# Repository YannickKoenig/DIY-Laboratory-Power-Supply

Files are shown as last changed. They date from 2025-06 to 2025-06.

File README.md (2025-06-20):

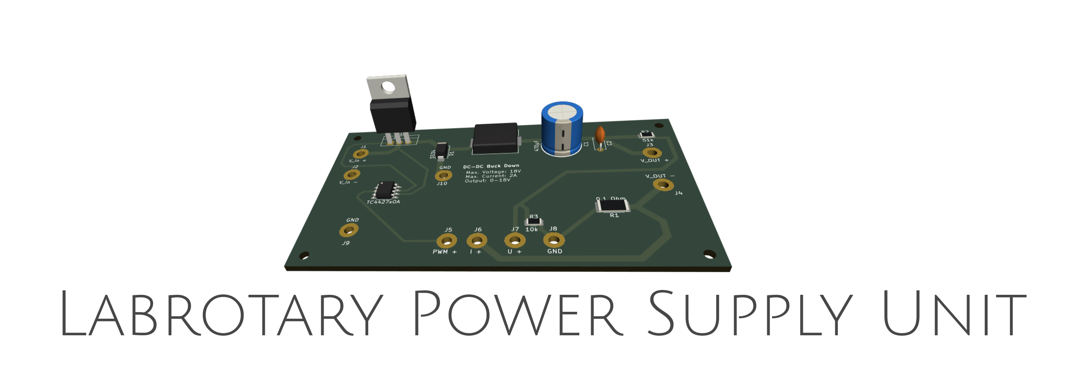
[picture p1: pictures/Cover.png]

# DIY Laboratory Power Supply Unit
A simple, microcontroller-based PWM buck converter power supply, designed to provide precise voltage control and current measurement. The output voltage is easily adjustable using a rotary encoder for accurate and intuitive input. This project is compact, affordable, and perfect for DIY laboratory power supply applications.

## Features
- Voltage regulation via PWM buck converter
- User-friendly voltage adjustment using a rotary encoder
- Real-time display of voltage and current
- Custom PCB Boards
- Compact and cost-effective design (~9€)

## Table of Contents  
- [BOM](#bom)
- [Assembly](#assembly)  
- [Usage](#usage)  
- [Contributing](#contributing)  
- [License](#license)
- [Schematics](#schematics)

## Bill of Materials (BOM)

| Item | Description | Quantity | Price | Total |
|---|---|---|---|---|
| KY-040 | Rotary Encoder | 1 | 0,89 €  | 0,89 €  |
| IRLZ44N | MOSFET-Transistor (TO-220) | 1 | 0,22 €  | 0,22 €  |
| Fuse (2A) | 5x20mm Glass Fuse | 1 | 0,03 €  | 0,03 €  |
| SS34 | Schottky Diode | 1 | 0,02 €  | 0,02 €  |
| TM1637 | 4-digit 7-segment LED Display | 2 | 1,90 €  | 3,80 €  |
| DC Plug | - | 1 | 0,24 €  | 0,24 €  |
| Power Switch | - | 1 | 0,12 €  | 0,12 €  |
| TC4427 | MOSFET Driver (SOP-8) | 1 | 0,29 €  | 0,29 €  |
| Buck Converter PCB | Custom PCB for Buck Converter | 1 | 0,08 €  | 0,08 €  |
| Frontend PCB (optional)| Custom PCB for Input & Displays | 1 | 0,80 €  | 0,80 €  |
| Raspberry Pi Pico | Microcontroller | 1 | 2,00 €  | 2,00 €  |
| Electrolytic Capacitor  | 470µF | 1 | 0,30 €  | 0,30 €  |
| Ceramic Capacitor | 1µF | 1 | 0,10 €  | 0,10 €  |
| Inductor | CD75, 47UH | 1 | 0,10 €  | 0,10 €  |
| SMD Resistor | Values 51k and 10k (1206) | 2 | 0,01 €  | 0,02 €  |
| SMD Resistor | Value 0.1 Ohm (2512) | 1 | 0,01 €  | 0,01 €  |

**Total: 9,01 €**

## Assembly
1. **Order the PCBs**:
For easier and cleaner assembly, it is recommended to order the PCBs from manufacturers like JLCPCB, PCBWAY, or AllPCB. Both the Buck Converter PCB and the optional Frontend PCB can be used. Just upload the appropriate Gerber files ([buckdown-pcb](hardware/electrical/buck-converter/Gerber), [frontend-pcb](hardware/electrical/frontend/Gerber))
2. **Solder the components**:
Carefully solder all the required components. The project includes both SMD and THT parts, so make sure you have the right tools and technique.
3. **Flash the microcontroller**:
-   Connect the Raspberry Pi Pico to your computer while holding the **BOOTSEL** button during startup.
-   You can either compile the firmware yourself or simply upload the precompiled `.uf2` file provided in the **releases** section.

4. **Connect the wiring**:
-   Connect the **Buck Converter PCB** and the **Frontend PCB** (if used) using the following connections:
    
    -   `GND` → `GND`
        
    -   `I+` → `I_in`
        
    -   `U+` → `U_in`
        
-   Connect the output of the Buck Converter:
    
    -   `V_out+` → Positive output terminal (e.g., banana plug).
        
    -   `V_out-` → Negative output terminal (e.g., banana plug).

You can use banana plugs, terminal blocks, or any other suitable connectors for your output.

-   If using the **Frontend PCB**, connect both **TM1637 displays** and the **rotary encoder** to the appropriate headers.
    
-   Make sure to add a **fuse (e.g., 2A)** to protect your circuit from potential damage.
    
-   To power the **Raspberry Pi Pico**, you can either:
    
    -   Power it via **USB**, or
        
    -   Use a separate **buck converter module** (e.g., LM2596S) connected in parallel with the DC input.

## Usage
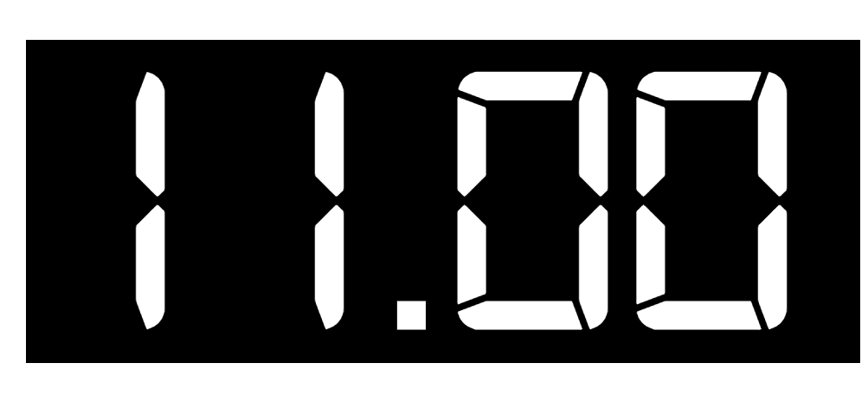
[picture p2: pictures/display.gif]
display


To adjust the output voltage:

- Turn the rotary encoder **left** to decrease the selected digit.
- Turn it **right** to increase the selected digit.
- Press the rotary encoder to switch between digits.

You can fine-tune the PI controller parameters (`K_P` and `K_I`) experimentally in the firmware to improve voltage regulation stability and response. See [RegulatorManager.hpp](./software/RegulatorManager.hpp) for details.

## Contributing

Contributions are welcome! Feel free to fork this project, submit pull requests, or open issues for improvements and bug fixes.

## Third-Party Libraries

This project uses the following third-party software:

- **Raspberry Pi Pico SDK**  
  Official SDK for Raspberry Pi Pico microcontroller.  
  License: BSD 3-Clause  
  [https://github.com/raspberrypi/pico-sdk](https://github.com/raspberrypi/pico-sdk)

- **TM1637_lib**  
  Library for controlling TM1637 7-segment displays.  
  License: MIT  
  [https://github.com/gavinlyonsrepo/displaylib_LED_PICO](https://github.com/gavinlyonsrepo/displaylib_LED_PICO)

## License

This project is open-source and available under the [MIT License](LICENSE.md).

## Schematics

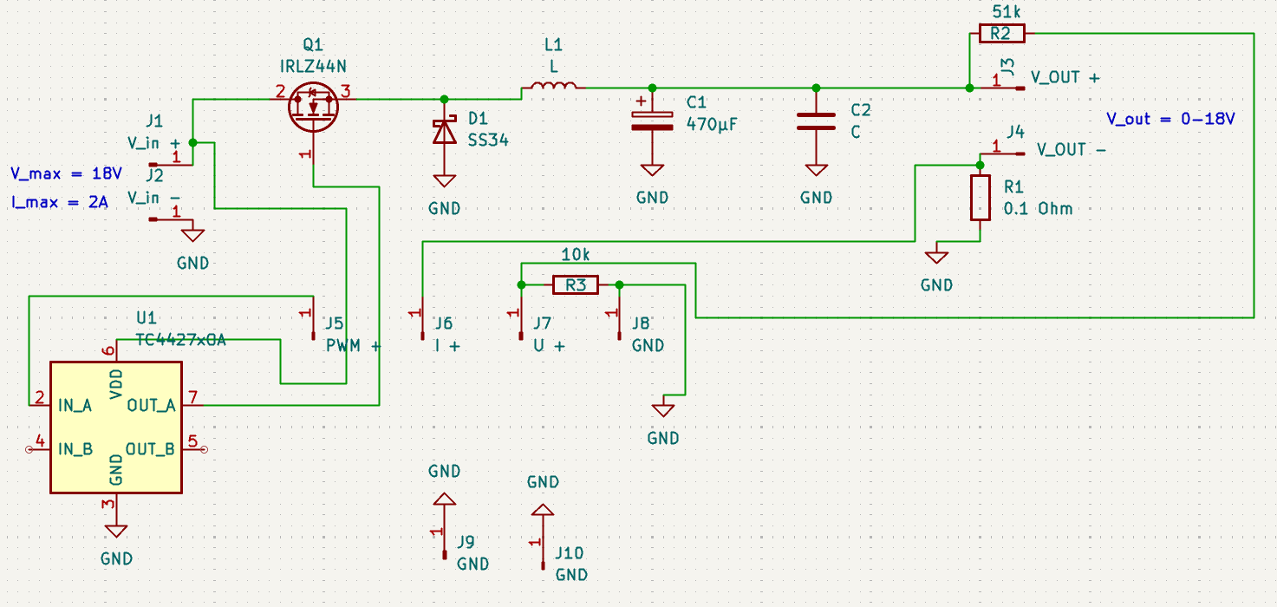
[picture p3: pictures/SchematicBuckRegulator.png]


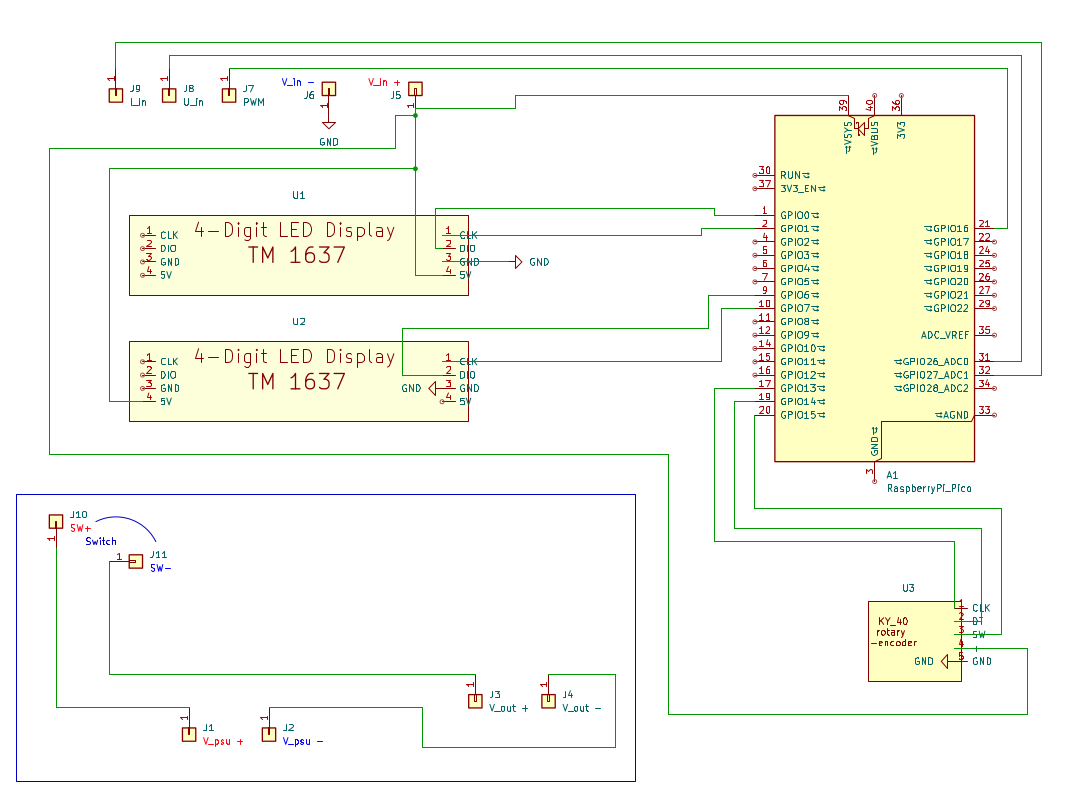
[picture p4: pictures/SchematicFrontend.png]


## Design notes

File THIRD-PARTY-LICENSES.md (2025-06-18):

# Third-Party Licenses

This project uses the following third-party software components. The licenses for these components are included below.

## Raspberry Pi Pico SDK
- License: BSD 3-Clause
- Repo: https://github.com/raspberrypi/pico-sdk

### BSD 3-Clause License Text
Copyright 2020 (c) 2020 Raspberry Pi (Trading) Ltd.

Redistribution and use in source and binary forms, with or without modification, are permitted provided that the
following conditions are met:

1. Redistributions of source code must retain the above copyright notice, this list of conditions and the following
   disclaimer.

2. Redistributions in binary form must reproduce the above copyright notice, this list of conditions and the following
   disclaimer in the documentation and/or other materials provided with the distribution.

3. Neither the name of the copyright holder nor the names of its contributors may be used to endorse or promote products
   derived from this software without specific prior written permission.

THIS SOFTWARE IS PROVIDED BY THE COPYRIGHT HOLDERS AND CONTRIBUTORS "AS IS" AND ANY EXPRESS OR IMPLIED WARRANTIES,
INCLUDING, BUT NOT LIMITED TO, THE IMPLIED WARRANTIES OF MERCHANTABILITY AND FITNESS FOR A PARTICULAR PURPOSE ARE
DISCLAIMED. IN NO EVENT SHALL THE COPYRIGHT HOLDER OR CONTRIBUTORS BE LIABLE FOR ANY DIRECT, INDIRECT, INCIDENTAL,
SPECIAL, EXEMPLARY, OR CONSEQUENTIAL DAMAGES (INCLUDING, BUT NOT LIMITED TO, PROCUREMENT OF SUBSTITUTE GOODS OR
SERVICES; LOSS OF USE, DATA, OR PROFITS; OR BUSINESS INTERRUPTION) HOWEVER CAUSED AND ON ANY THEORY OF LIABILITY,
WHETHER IN CONTRACT, STRICT LIABILITY, OR TORT (INCLUDING NEGLIGENCE OR OTHERWISE) ARISING IN ANY WAY OUT OF THE USE OF
THIS SOFTWARE, EVEN IF ADVISED OF THE POSSIBILITY OF SUCH DAMAGE.

## TM1637_lib
- License: MIT
- Repo: https://github.com/gavinlyonsrepo/displaylib_LED_PICO

### MIT License Text

 Permission is hereby granted, free of charge, to any person obtaining a copy
 of this software and associated documentation files (the "Software"), to deal
 in the Software without restriction, including without limitation the rights
 to use, copy, modify, merge, publish, distribute, sublicense, and/or sell
 copies of the Software, and to permit persons to whom the Software is
 furnished to do so, subject to the following conditions:

 The above copyright notice and this permission notice shall be included in all
 copies or substantial portions of the Software.

 THE SOFTWARE IS PROVIDED "AS IS", WITHOUT WARRANTY OF ANY KIND, EXPRESS OR
 IMPLIED, INCLUDING BUT NOT LIMITED TO THE WARRANTIES OF MERCHANTABILITY,
 FITNESS FOR A PARTICULAR PURPOSE AND NONINFRINGEMENT. IN NO EVENT SHALL THE
 AUTHORS OR COPYRIGHT HOLDERS BE LIABLE FOR ANY CLAIM, DAMAGES OR OTHER
 LIABILITY, WHETHER IN AN ACTION OF CONTRACT, TORT OR OTHERWISE, ARISING FROM,
 OUT OF OR IN CONNECTION WITH THE SOFTWARE OR THE USE OR OTHER DEALINGS IN THE
 SOFTWARE.

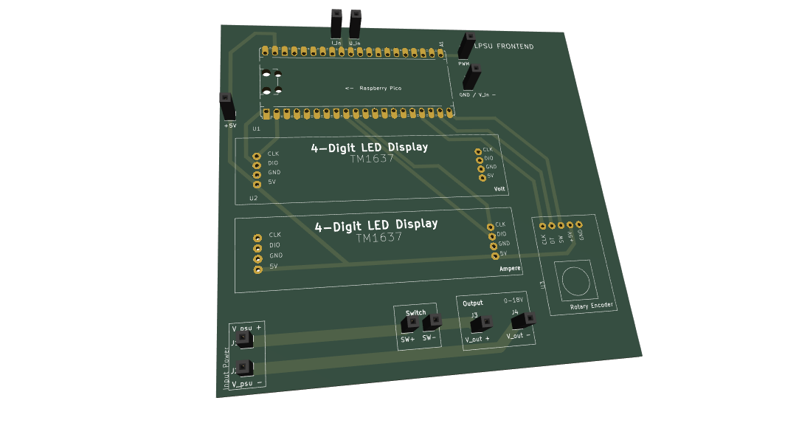
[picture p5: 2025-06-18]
pictures/FrontendPCB.png

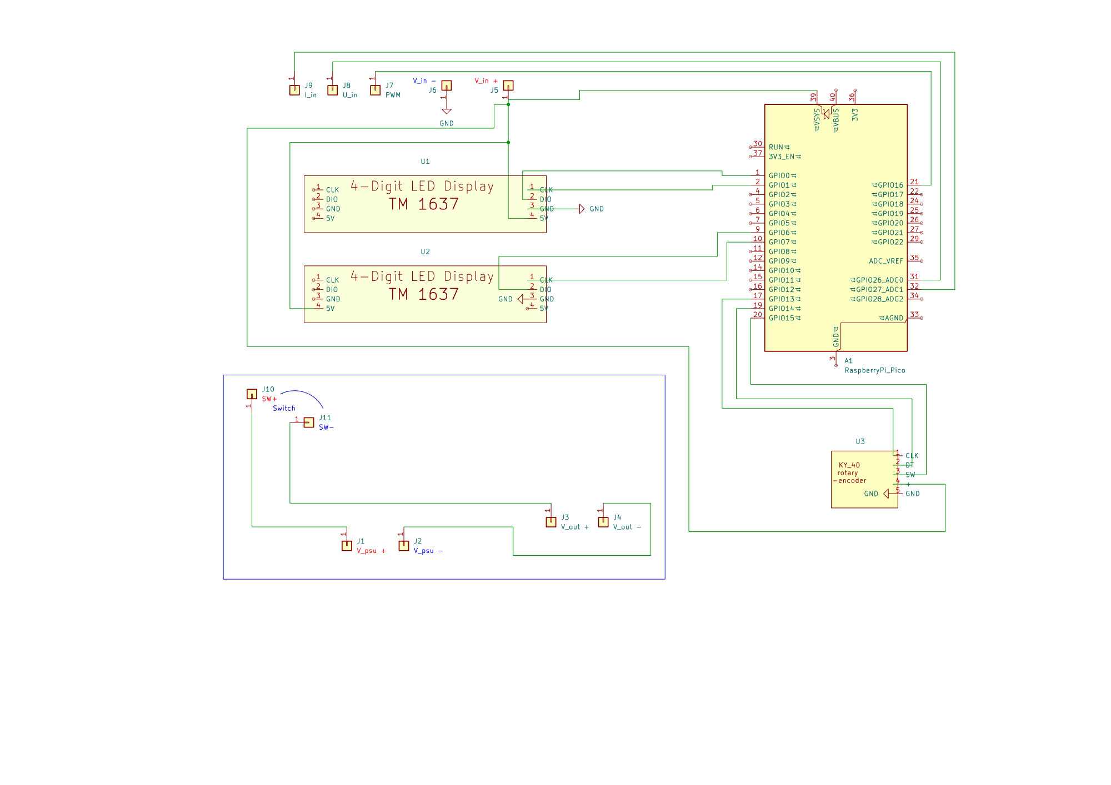
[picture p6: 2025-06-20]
pictures/Download.png

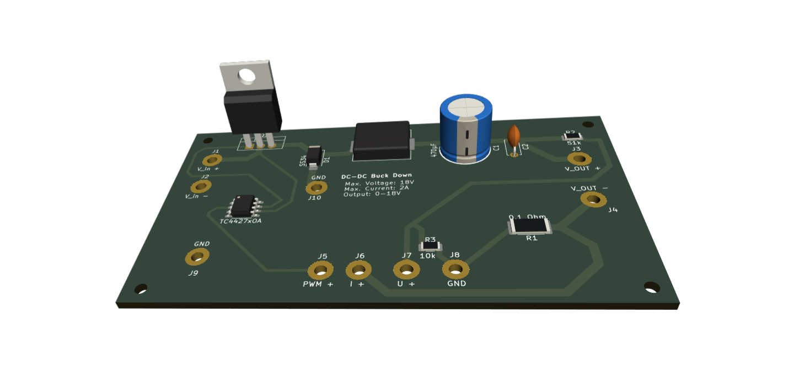
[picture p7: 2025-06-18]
pictures/BuckDownPCB.png

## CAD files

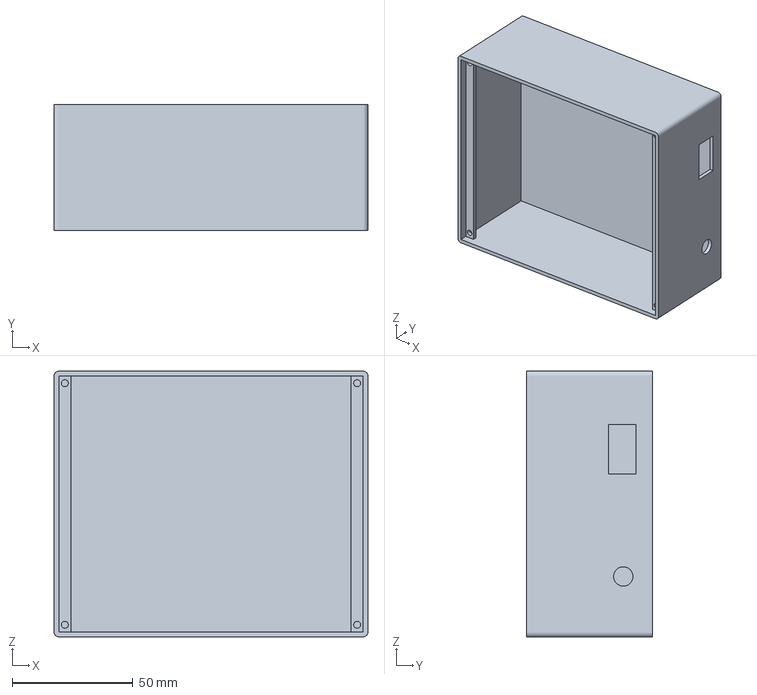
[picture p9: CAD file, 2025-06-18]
hardware/mechanical/Base.3mf
130.0 x 52.0 x 110.0 mm

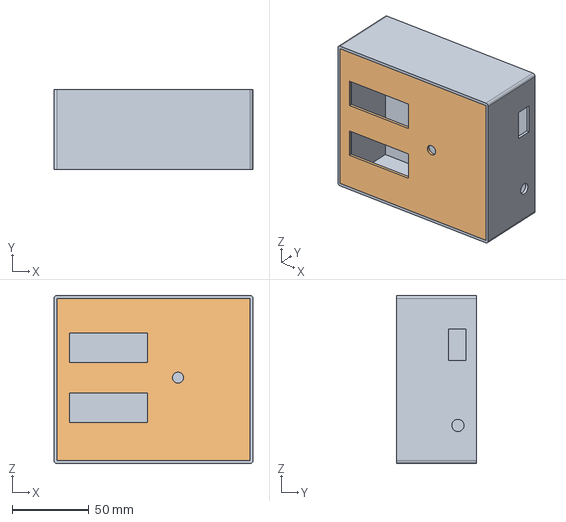
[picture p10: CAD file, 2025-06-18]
hardware/mechanical/FreeCAD.FCStd
130.0 x 52.0 x 110.0 mm
Base

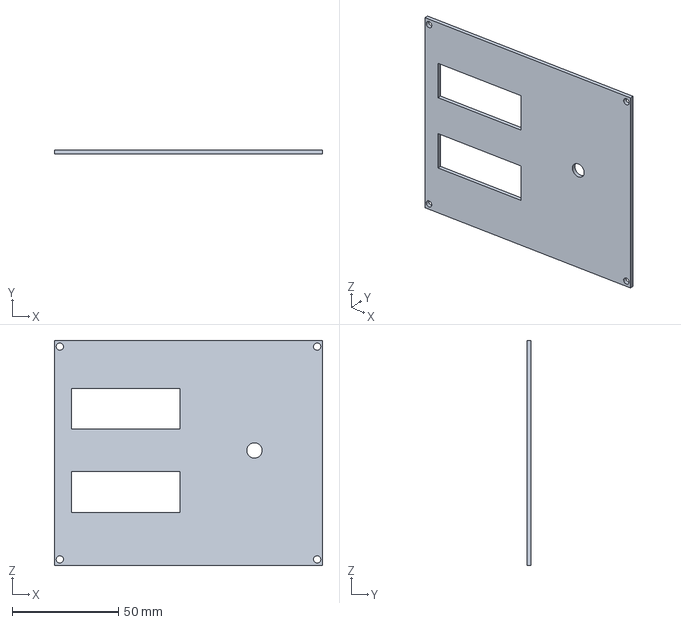
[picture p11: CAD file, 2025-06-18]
hardware/mechanical/Top.3mf
126.0 x 2.00 x 106.0 mm

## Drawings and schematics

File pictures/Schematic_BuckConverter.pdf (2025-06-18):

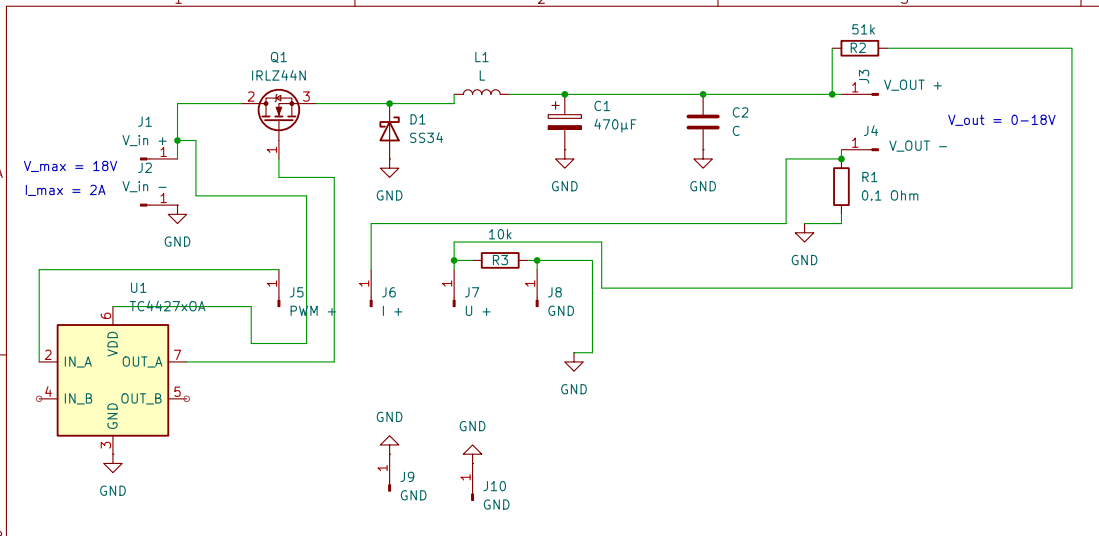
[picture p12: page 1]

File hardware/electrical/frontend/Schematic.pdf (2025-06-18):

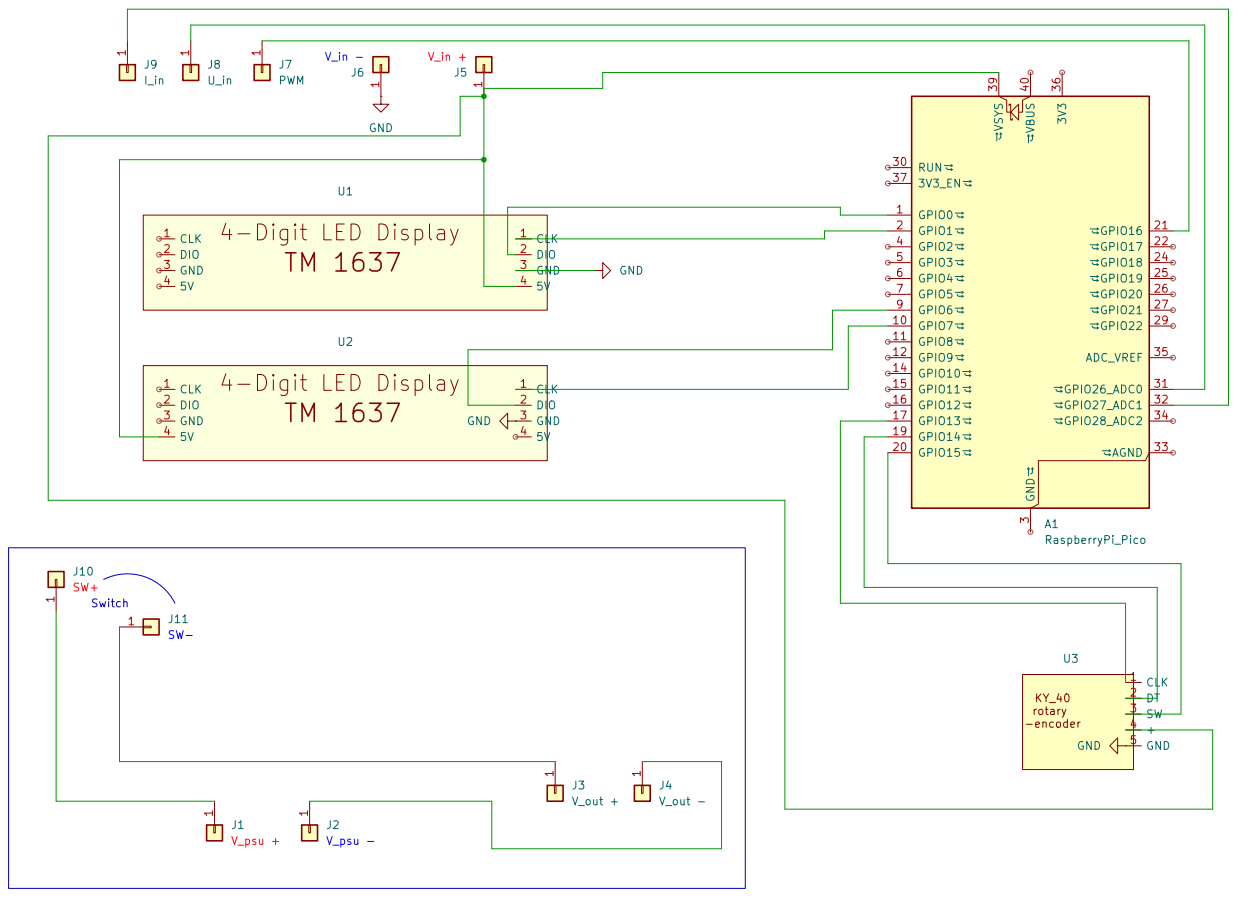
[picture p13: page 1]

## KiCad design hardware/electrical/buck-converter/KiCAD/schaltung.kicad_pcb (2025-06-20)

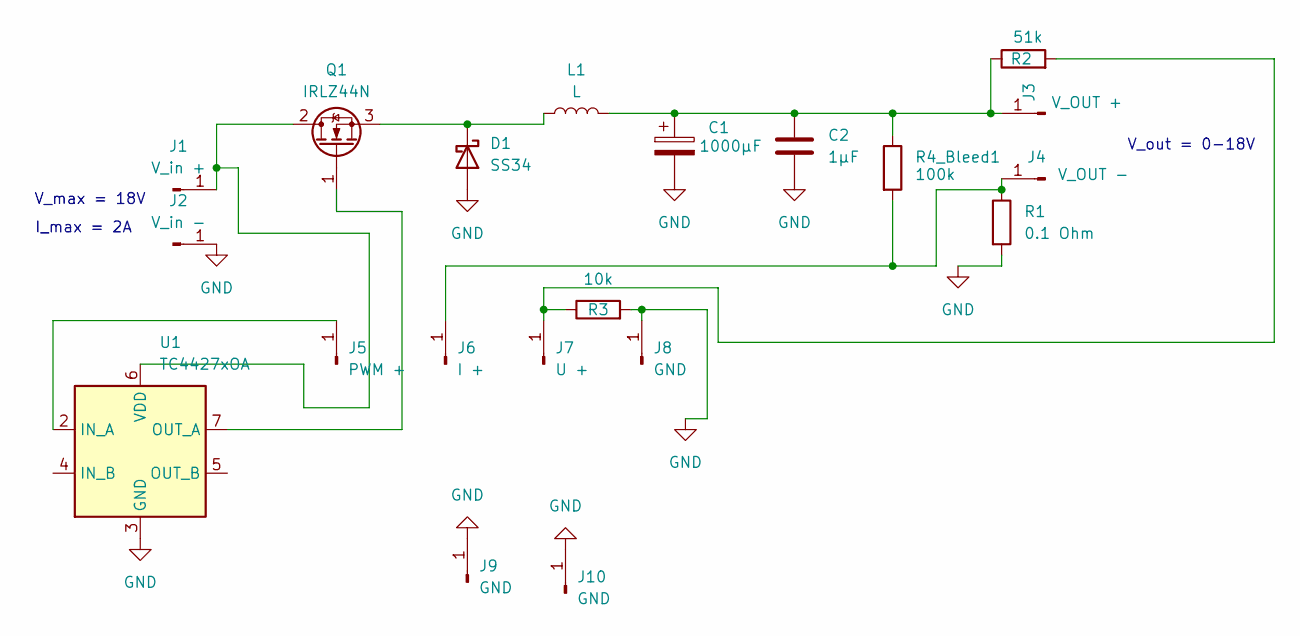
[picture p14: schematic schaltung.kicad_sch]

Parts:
C1: 1000µF; CP_Radial_D10.0mm_P5.00mm
C2: 1µF; C_Disc_D5.0mm_W2.5mm_P5.00mm
D1: SS34; D_SMA
J1: V_in +; MountingHole_2.2mm_M2_Pad
J2: V_in -; MountingHole_2.2mm_M2_Pad
J3: V_OUT +; MountingHole_2.2mm_M2_Pad
J4: V_OUT -; MountingHole_2.2mm_M2_Pad
J5: PWM +; MountingHole_2.2mm_M2_Pad
J6: I +; MountingHole_2.2mm_M2_Pad
J7: U +; MountingHole_2.2mm_M2_Pad
J8, J9, J10: GND; MountingHole_2.2mm_M2_Pad
L1: L; L_Sunlord_MWSA1003S
Q1: IRLZ44N; TO-220-3_Vertical
R1: 0.1 Ohm; R_2512_6332Metric
R2: 51k; R_1206_3216Metric
R3: 10k; R_1206_3216Metric
R4_Bleed1: 100k; R_1206_3216Metric
U1: TC4427xOA; SOIC-8_3.9x4.9mm_P1.27mm

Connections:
GND: C1.2, C2.2, D1.2 (A), J2.1, J8.1, J9.1, J10.1, R1.2, R3.2, U1.3 (GND)
unnamed: D1.1 (K), L1.1, Q1.3 (S)
unnamed: J1.1, Q1.2 (D), U1.6 (VDD)
unnamed: C1.1, C2.1, J3.1, L1.2, R2.1, R4_Bleed1.1
unnamed: J4.1, J6.1, R1.1, R4_Bleed1.2
unnamed: J5.1, U1.2 (IN_A)
unnamed: J7.1, R2.2, R3.1
unnamed: Q1.1 (G), U1.7 (OUT_A)

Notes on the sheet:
I_max = 2A
V_max = 18V
V_out = 0-18V

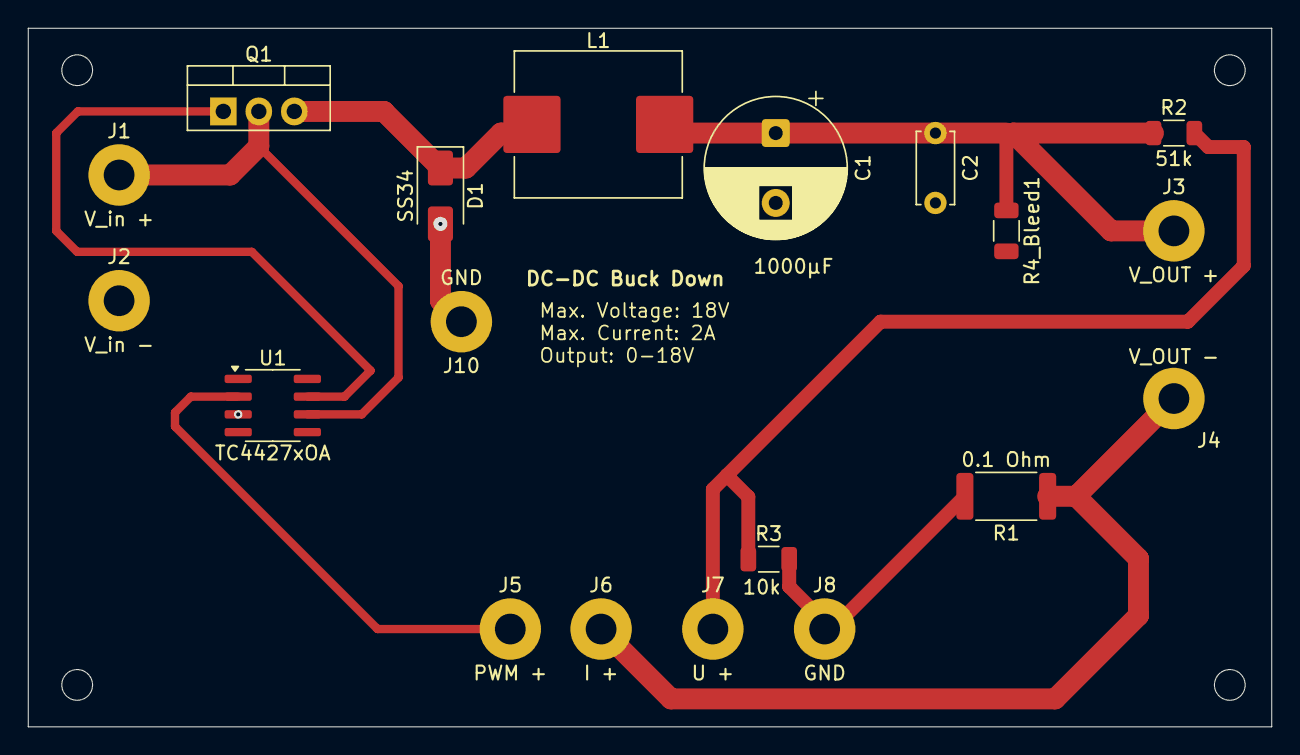
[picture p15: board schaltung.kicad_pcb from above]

Board: 2 copper layers, 89.0 x 50.0 mm, 20 parts (0 on the bottom side), 8 nets.

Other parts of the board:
REF1: MountingHole_2.2mm_M2

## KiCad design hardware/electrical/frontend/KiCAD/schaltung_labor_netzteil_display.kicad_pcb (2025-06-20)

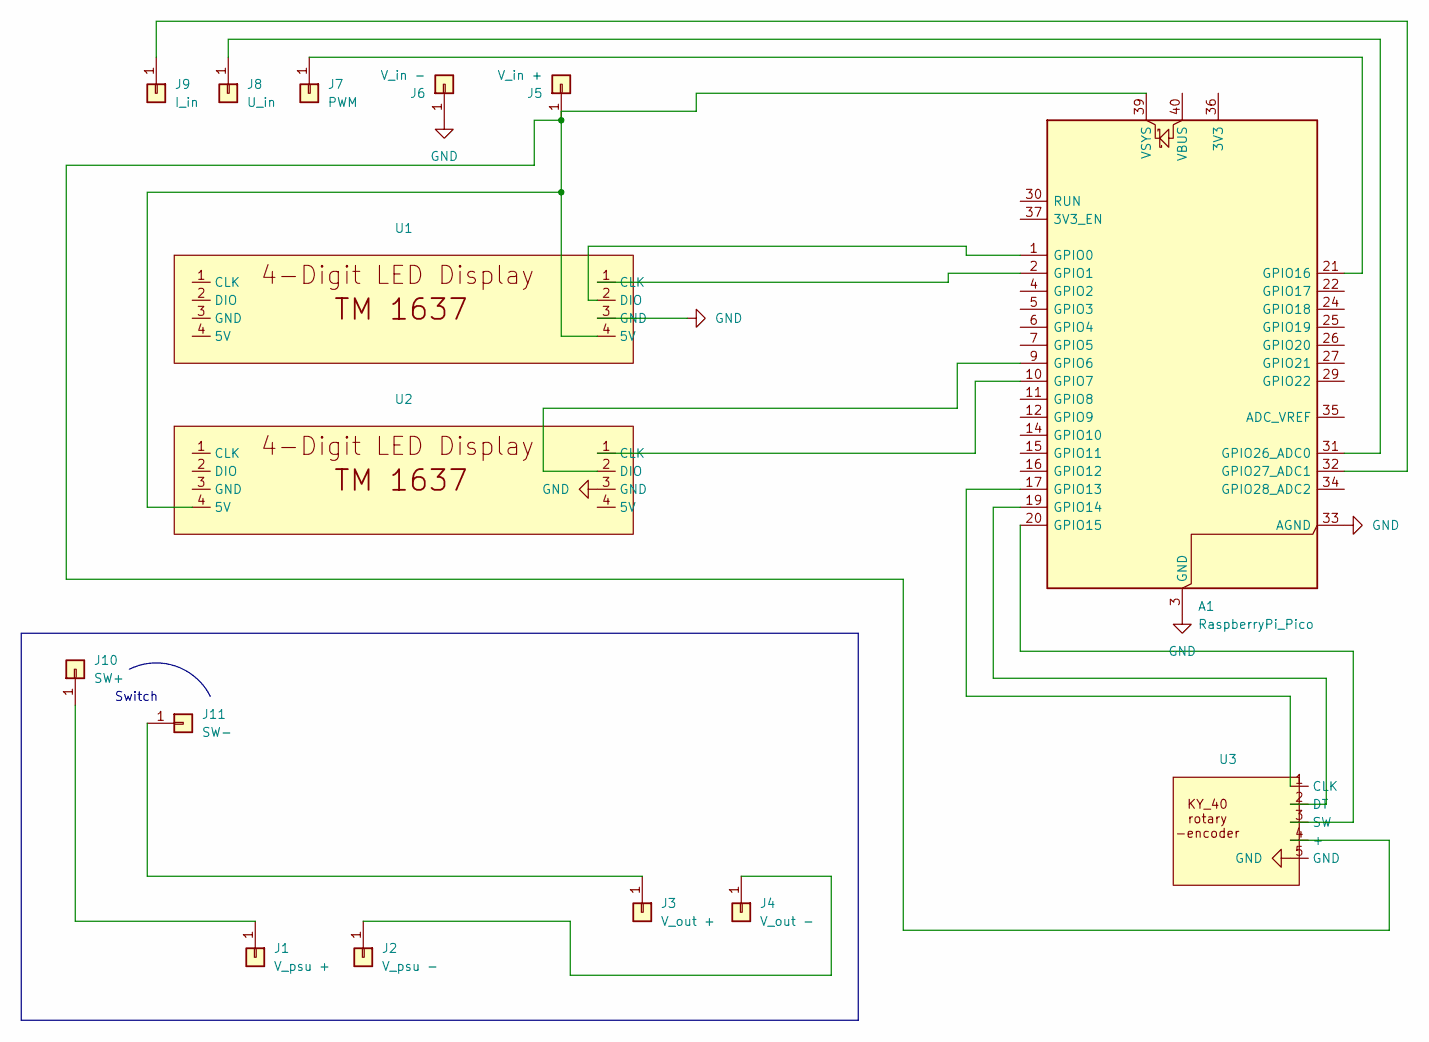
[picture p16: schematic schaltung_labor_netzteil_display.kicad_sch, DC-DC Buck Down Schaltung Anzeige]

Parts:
A1: RaspberryPi_Pico; RaspberryPi_Pico_Common_Unspecified
J1: V_psu +; PinSocket_1x01_P2.54mm_Vertical
J2: V_psu -; PinSocket_1x01_P2.54mm_Vertical
J3: V_out +; PinSocket_1x01_P2.54mm_Vertical
J4: V_out -; PinSocket_1x01_P2.54mm_Vertical
J5: V_in +; PinSocket_1x01_P2.54mm_Vertical
J6: V_in -; PinSocket_1x01_P2.54mm_Vertical
J7: PWM; PinSocket_1x01_P2.54mm_Vertical
J8: U_in; PinSocket_1x01_P2.54mm_Vertical
J9: I_in; PinSocket_1x01_P2.54mm_Vertical
J10: SW+; PinSocket_1x01_P2.54mm_Vertical
J11: SW-; PinSocket_1x01_P2.54mm_Vertical
U1, U2: TM1637
U3: KY_40

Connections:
GND: A1.3 (GND), A1.8 (GND), A1.13 (GND), A1.18 (GND), A1.23 (GND), A1.28 (GND), A1.33 (AGND), A1.38 (GND), J6.1, U1.3 (GND), U2.3 (GND), U3.5 (GND)
unnamed: A1.1 (GPIO0), U1.2 (DIO)
unnamed: A1.2 (GPIO1), U1.1 (CLK)
unnamed: A1.9 (GPIO6), U2.2 (DIO)
unnamed: A1.10 (GPIO7), U2.1 (CLK)
unnamed: A1.17 (GPIO13), U3.1 (CLK)
unnamed: A1.19 (GPIO14), U3.2 (DT)
unnamed: A1.20 (GPIO15), U3.3 (SW)
unnamed: A1.21 (GPIO16), J7.1
unnamed: A1.31 (GPIO26_ADC0), J8.1
unnamed: A1.32 (GPIO27_ADC1), J9.1
unnamed: A1.39 (VSYS), J5.1, U1.4 (5V), U2.4 (5V), U3.4 (+)
unnamed: J1.1, J10.1
unnamed: J2.1, J4.1
unnamed: J3.1, J11.1

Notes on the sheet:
Switch

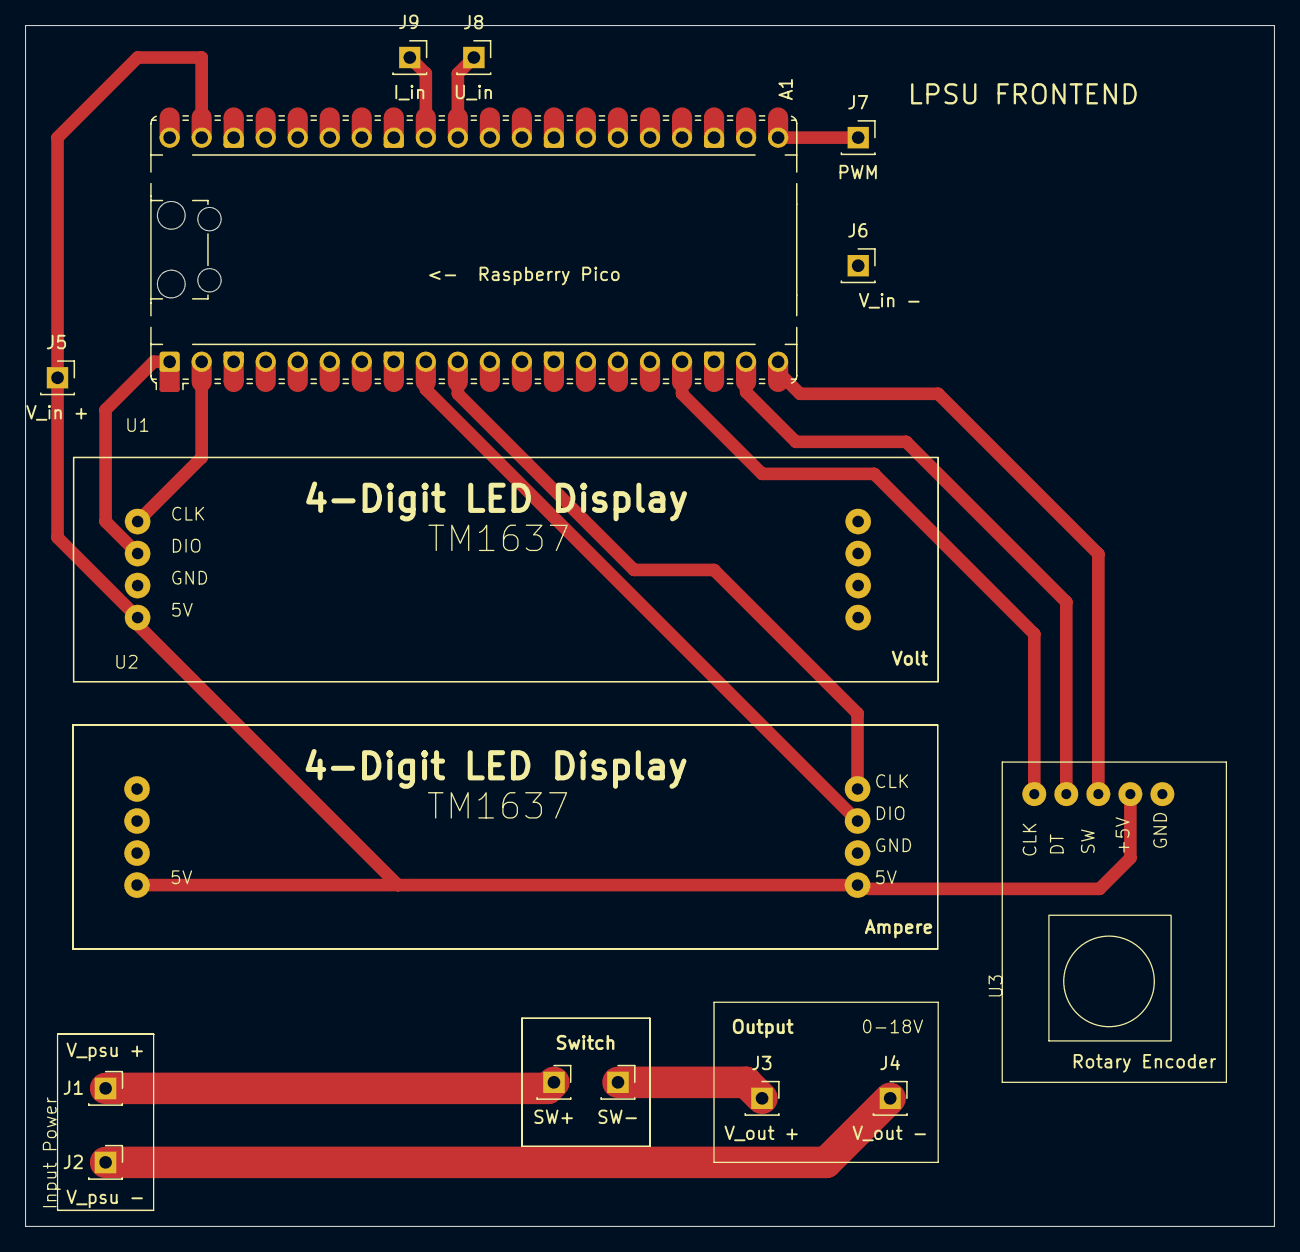
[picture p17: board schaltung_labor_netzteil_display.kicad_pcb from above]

Board: 2 copper layers, 99.1 x 95.2 mm, 15 parts (0 on the bottom side), 15 nets.

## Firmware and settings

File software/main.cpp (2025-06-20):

#include "pico/stdlib.h"
#include "displaylib_LED_PICO/include/displaylib_LED_PICO/tm1637.hpp"
#include "DisplayManager.hpp"
#include "RotaryEncoder.hpp"
#include "RegulatorManager.hpp"

#define DISPLAY_REFRESH_RATE_MS 100

DisplayManager *displayManager;
RotaryEncoder *rotaryEncoder;
RegulatorManager *regulatorManager;
absolute_time_t lastDisplayRefresh = {0};

void setup(void);
void loop(void);

int main()
{
    setup();
    loop();
    return 0;
}

void setup(void)
{
    stdio_init_all(); // Initialize USB Serial

    int values[] = {0, 5, 0, 0}; // Default Voltage: 5.00 V
    displayManager = new DisplayManager();
    rotaryEncoder = new RotaryEncoder(values, 1);
    regulatorManager = new RegulatorManager();
    regulatorManager->setTargetVoltage(5.0);
}

float calculateTargetVoltage(const int *values)
{
    return values[0] * 10.0 + values[1] * 1.0 + values[2] * 0.1 + values[3] * 0.01;
}

bool displayRefreshDue()
{
    return absolute_time_diff_us(lastDisplayRefresh, get_absolute_time()) > DISPLAY_REFRESH_RATE_MS * 1000;
}

void loop()
{
    while (true)
    {
        const int *values = rotaryEncoder->getValues();
        if (displayRefreshDue())
        {
            displayManager->update(values, rotaryEncoder->getSelectedDecimal());
            displayManager->setLastEdited(rotaryEncoder->getLastInterupt());
            displayManager->show();
            displayManager->setAmperage(regulatorManager->getAmperage());
            lastDisplayRefresh = get_absolute_time();
            regulatorManager->setTargetVoltage(calculateTargetVoltage(values));
        }

        regulatorManager->update(100);

        sleep_us(100);
    }
}

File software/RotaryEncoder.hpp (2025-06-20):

#pragma once

#include "pico/stdlib.h"
#include <stdio.h>

#define ENCODER_A_PIN 13
#define ENCODER_B_PIN 14
#define ENCODER_SW_PIN 15

#define DEBOUNCE_MS 255

class RotaryEncoder;

static RotaryEncoder *g_encoder = nullptr; // Ugly trick to get (the only) RotaryEncoder object to run the interupt

enum class RotDirection
{
    LEFT,
    RIGHT,
    CLICK
};

class RotaryEncoder
{
private:
    absolute_time_t last_interupt = {0};

    volatile bool last_A = false;          // Last known state of encoder pin A
    volatile bool last_B = false;          // Last known state of encoder pin B
    volatile int32_t encoder_position = 0; // (Unused currently, can be used for absolute pos)
    volatile int8_t selectedDecimal;       // Index of currently selected digit
    int values[4];                         // Array holding 4 digits of the value

public:
    RotaryEncoder(int newValues[4], int newSelectedDecimal)
        : selectedDecimal(newSelectedDecimal)
    {
        for (int i = 0; i < 4; ++i)
        {
            values[i] = newValues[i];
        }
        g_encoder = this;

        // GPIO setup
        gpio_init(ENCODER_A_PIN);
        gpio_set_dir(ENCODER_A_PIN, GPIO_IN);
        gpio_pull_up(ENCODER_A_PIN);

        gpio_init(ENCODER_B_PIN);
        gpio_set_dir(ENCODER_B_PIN, GPIO_IN);
        gpio_pull_up(ENCODER_B_PIN);

        gpio_init(ENCODER_SW_PIN);
        gpio_set_dir(ENCODER_SW_PIN, GPIO_IN);
        gpio_pull_up(ENCODER_SW_PIN);

        // printf("Setting interrupt");

        irq_set_enabled(IO_IRQ_BANK0, true);
        gpio_set_irq_callback(RotaryEncoder::interruptTriggered);
        gpio_set_irq_enabled(ENCODER_A_PIN, GPIO_IRQ_EDGE_FALL | GPIO_IRQ_EDGE_RISE, true);
        gpio_set_irq_enabled(ENCODER_B_PIN, GPIO_IRQ_EDGE_FALL | GPIO_IRQ_EDGE_RISE, true);
        gpio_set_irq_enabled(ENCODER_SW_PIN, GPIO_IRQ_EDGE_FALL, true);
    }
    absolute_time_t getLastInterupt()
    {
        return last_interupt;
    }

    bool interuptIsDebounced()
    {
        absolute_time_t now = get_absolute_time();
        bool valid = absolute_time_diff_us(last_interupt, now) > DEBOUNCE_MS * 1000;
        last_interupt = now;
        return valid;
    }
    void expressYourself()
    {
        printf("rot pos: %d\n", encoder_position);
    }
    void handleRotation(RotDirection rotDirection)
    {
        if (!interuptIsDebounced())
        {
            return;
        }

        switch (rotDirection)
        {
        case RotDirection::LEFT:
            values[selectedDecimal]--;
            encoder_position--;
            printf("Left Rotation");
            break;

        case RotDirection::RIGHT:
            values[selectedDecimal]++;
            encoder_position++;
            printf("Right Rotation");
            break;
        case RotDirection::CLICK:
            selectedDecimal++;
            if (selectedDecimal >= 4)
                selectedDecimal = 0;
            break;
        default:
            break;
        }
    }

    void checkValues()
    {
        constexpr int maxValues[4] = {1, 9, 9, 9};
        constexpr int minValue = 0;

        // Clamp each digit between min and max values
        for (int i = 0; i < 4; ++i)
        {
            if (values[i] < minValue)
                values[i] = minValue;
            else if (values[i] > maxValues[i])
                values[i] = maxValues[i];
        }

        // Calculate total numeric value from digits
        float total = values[0] * 10.0 + values[1] + values[2] * 0.1 + values[3] * 0.01;

        // Clamp total max to 18.00
        if (total > 18.00)
        {
            values[0] = 1;
            values[1] = 8;
            values[2] = 0;
            values[3] = 0;
        }
    }

    // Static ISR trampoline to call instance method
    static void interruptTriggered(uint gpio, uint32_t events)
    {
        // printf("interrupt triggered, gpio:%d\n\n\n", gpio);

        if (g_encoder)
            g_encoder->handleInterrupt(gpio, events);
    }
    // Actual interrupt handler updating state and calling rotation logic
    void handleInterrupt(uint gpio, uint32_t events)
    {

        bool A = gpio_get(ENCODER_A_PIN);
        bool B = gpio_get(ENCODER_B_PIN);

        if ((gpio == ENCODER_A_PIN && A != last_A) || (gpio == ENCODER_B_PIN && B != last_B))
        {
            bool directionLeft = (gpio == ENCODER_A_PIN) ? (A == B) : (A != B);

            handleRotation(directionLeft ? RotDirection::LEFT : RotDirection::RIGHT);

            if (gpio == ENCODER_A_PIN)
                last_A = A;
            else
                last_B = B;
        }
        else if (gpio == ENCODER_SW_PIN)
        {
            handleRotation(RotDirection::CLICK);
        }
    }

    const int *getValues()
    {
        checkValues();
        return values;
    }

    int8_t getSelectedDecimal() const
    {
        return selectedDecimal;
    }
};

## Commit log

2025-06-18 added readme
    [BOM.xlsx]
2025-06-18 Improved folder structure
    [Base.3mf, FreeCAD.FCStd, Top.3mf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]
2025-06-18 Updated images
    [BOM.xlsx]
2025-06-19 Update RegulatorManager.cpp
    Corrected current calculation
    [RegulatorManager.cpp]
2025-06-20 Updated PCBs; added Bleed Resistor and fixed Frontend GND connections
    [schaltung-B_Cu.gbl, schaltung-B_Mask.gbs, schaltung-B_Paste.gbp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]
2025-06-20 Repaired PWM frequency
